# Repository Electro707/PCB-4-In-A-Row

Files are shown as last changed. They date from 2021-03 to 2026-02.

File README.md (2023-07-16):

# PCB Digital 4-In-A-Row

This a PCB is a soldering kit for a 4-In-A-Row game. A simple game consisting of 2 boards: one for the driver and one for the LEDs.

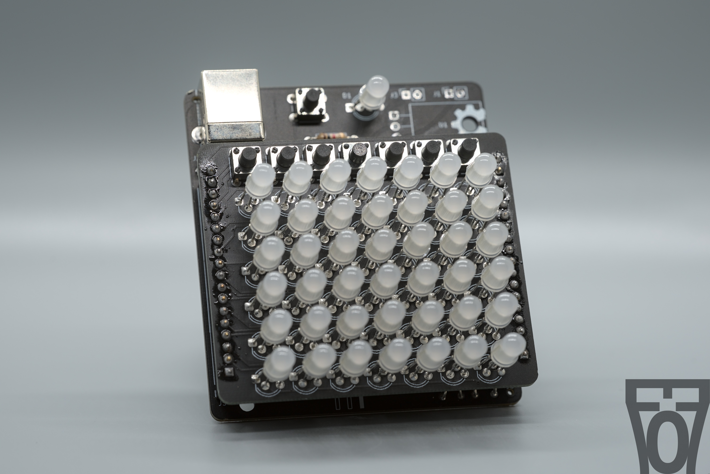
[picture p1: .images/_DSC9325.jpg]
Latest Rev


## Kits Page
The dedicated webpage for this can be found at [https://kits.electro707.com/4_in_a_row/](https://kits.electro707.com/4_in_a_row/)

## Kit on Tindie
I am currently selling the kit on Tindie. The product page can be found at [https://www.tindie.com/products/28121/](https://www.tindie.com/products/28121/).

## Firmware
The firmware can be found in the [Firmware](Firmware) folder. To build and upload the program, see [FIRMWARE.md](FIRMWARE.md) for more details.

## License
This project is licensed under the MIT license. See the [LICENSE.md](LICENSE.md) file for details.
TL;DR: You can download and modify the project as you wish. I simply ask you publish your fork or try and merge back to this repo (even thought you are under no obligations to do so).

## Changelog 
See [CHANGELOG.md](CHANGELOG.md) for changes info.

## Previous/Archived Repo
This project used to be in another repo before I archived it. The reason for the archive is I wanted to start properly using git as a version manager (instead of different folders) as well as a project cleanup. Think of it as a new start to this project.
The previous project repo can be found here: [https://github.com/Electro707/PCB-4-In-A-Row-ARCHIVE](https://github.com/Electro707/PCB-4-In-A-Row-ARCHIVE)

## Other Images

Latest Rev

With Panel (not actually updated, just made it once):
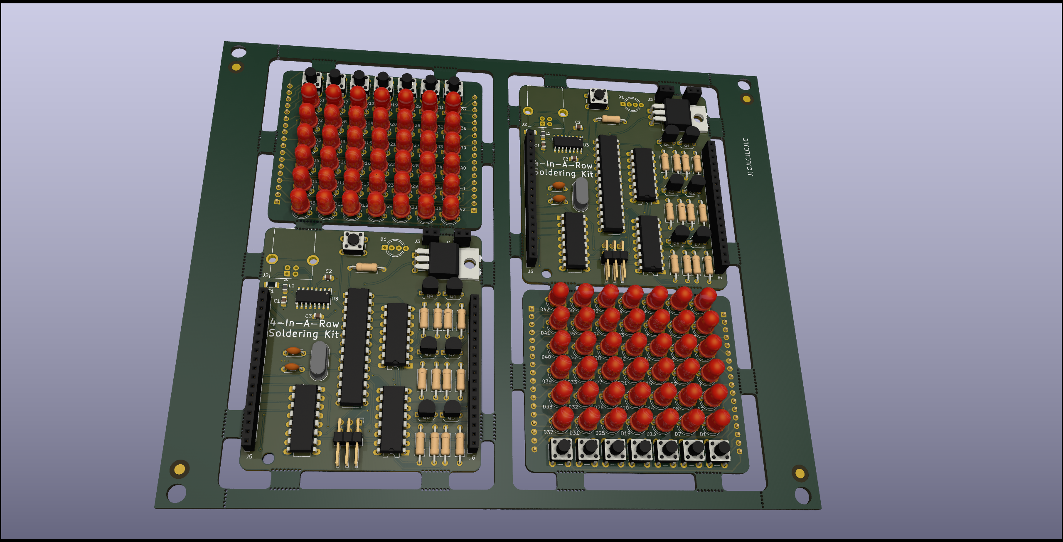
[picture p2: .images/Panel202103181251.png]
Panel Picture


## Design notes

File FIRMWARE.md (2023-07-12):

# Firmware Notes
This is the firwmare for the 4-in-a-row soldering kit. The revision number can be found in the git tags in this repository, tagged with fw_xxx.

## Arduino Comaptibility
The firmware is originally designed to only be built with the make file. With that said, the firmare is designed to be compatible with the Arduino IDE to build and upload. Just open [Firmware.ino](Firmware/Firmware.ino) with the IDE.
To upload the program, it is recommended to use the [MiniCore](https://github.com/MCUdude/MiniCore) hardware package to build and program to the IC. If using that, ensure that the external 16Mhz clock (default) is selected for the Clock setting.

## Build Requirements (non-Arduino)
If you would like to use the makefile to program and upload this firmware, you would need `avr-gcc` and `avrdude`. They can be downloaded from your package repository if you are using a sane operating system (GNU/Linux). If you are using MacOS, you should be able to get them thru brew, but I haven't checked. If you are on Windows, good luck!

## Make Commands:
- *default/no arguments*: **build** and **size**
- quick: **build** -> **size** -> **program**
- build: Builds the firmware
- size: Shows the RAM and FLASH usage of the built firmware
- program: Uploads the firmware over Arduino-As-ISP over /dev/ttyUSB0. To modify this, edit the makefile
- clean: Cleans the build files
- docs: Builds the doxygen documentation page

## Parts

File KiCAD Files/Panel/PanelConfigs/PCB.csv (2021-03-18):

Comment | Designator | Footprint | LCSC
100nF | C1,C2,C3 | Capacitor_SMD:C_0805_2012Metric_Pad1.18x1.45mm_HandSolder | C49678
Polyfuse | F1 | Fuse:Fuse_1206_3216Metric_Pad1.42x1.75mm_HandSolder | C369159
BLM21AG102SN1D | L1 | Inductor_SMD:L_0805_2012Metric_Pad1.15x1.40mm_HandSolder | C97001
CH340C | U3 | Package_SO:SOIC-16_3.9x9.9mm_P1.27mm | C84681

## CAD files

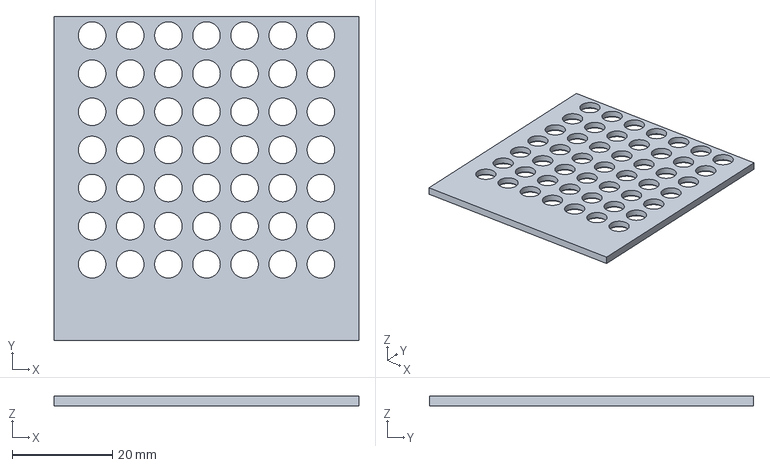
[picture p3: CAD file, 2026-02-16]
CAD/LED-Holder-Fixture/LedFixture.FCStd
61.0 x 64.8 x 2.00 mm

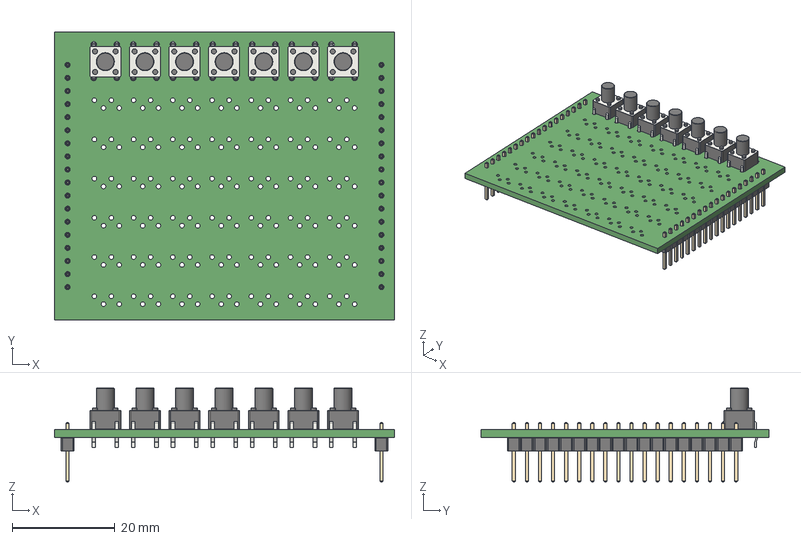
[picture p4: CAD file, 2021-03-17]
KiCAD Files/LED PCB/LED_PCB.step
66.0 x 55.9 x 18.2 mm

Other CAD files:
CAD/LED-Holder-Fixture/LedFixture-BodyChamfer.stl

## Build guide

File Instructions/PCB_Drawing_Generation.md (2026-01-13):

# How to generate drawings of the PCBs

To generate the top-down view of the PCBs, simply run `generate_pcb_svg.sh`.

To generate the step-by-step instructions, run:
`pcbdraw populate populate_driver.md step_by_step`.

You will need [pcbdraw](https://github.com/yaqwsx/PcbDraw) installed, preferable [my fork](https://github.com/Electro707/PcbDraw) as I incorporated some fixes.

On top of that, you will also need my [pcbdraw-lib fork](https://github.com/Electro707/PcbDraw-Lib/tree/e707) on the `e707` branch. You will need to modify the generate script to point "/home/electro/Documents/git/PcbDraw-Lib/KiCAD-base" to the location of the downloaded pcbdraw-lib fork. I do plan on creating PRs to merge the drawings I made upstream.

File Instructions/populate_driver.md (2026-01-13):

---
params:
    - --remap "../KiCAD Files/Driver PCB/pcbdraw_remap.json"
    - --resistor-flip "R15,R14,R13,R12,R11,R10"
    - --libs /mnt/aux1/git/PcbDraw-Lib/KiCAD-base
    - -s set-black-hasl
imgname: step_drawings/populating_{}.png
template: html_template
type: html
board: "../KiCAD Files/Driver PCB/PCB.kicad_pcb"
initial_components:
    - F1
    - L1
    - C1
...

# Soldering Guide - Main Driver

This page guides you through soldering a 4-in-a-row kit's main board, step by step.

These steps are my recommendation, but feel free to deviate of a certain order is easier for you!

- [[front | ]] We get the empty board
- [[front | R3-R9]] I recommend to solder all resistors first, as they are the thinest component and thus you can lay the board down with the resistors populated while soldering. I started with 1k&#8486; resistors, but you can choose any order
- [[front | R10-R15]] Then we solder the next set of resistor values, which are 100&#8486;
- [[front | Q1-Q6]] Then we populate all 2N3904 transistors
- [[front | C4-C5]] We populate the 12pF capacitors for the crystal
- [[front | Y1]] And then the crystal itself
- [[front | U2-U6]] Then we populate the ICs. In this drawing, the ICs are directly shown. THIS IS NOT RECOMMENDED. Instead, use the pin headers, and then push the component into them.
- [[front | SW1]] Then we populate the switch
- [[front | D1]] And the main indicator diode
- [[front | J2]] The USB connector
- [[front | J5,J6]] Then finally, the side pin sockets that will interconnect to the main board
- [[front | U1]] OPTIONALLY, solder U1 if you intend to use an external 7-12v source (such as a 9v battery)

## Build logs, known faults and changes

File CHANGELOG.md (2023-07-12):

This document describes the changes between the different revision. There is a previous [OLDER REPO](https://github.com/Electro707/PCB-4-In-A-Row-ARCHIVE) for this project, as mentioned in this repo's [README.md](../README.md)

- PCB rev:
    - V0.9: Initial commit to this repo (used to be known as RevB5 in the previous repo). The reason it's not a 1.0 is because I would to order a test board before releasing the design as complete.
    - V1.0: Initial completed release
- Firmware rev:
    - V0.9: Initial commit to this repo (used to be known as RevB5 in the previous repo). The reason it's not a 1.0 is because I want to test the firmware with the upcomming V1.0 of the board before a 1.0 release.
    - V1.0: Initial completed release

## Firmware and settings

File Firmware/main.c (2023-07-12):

/**
 * \mainpage
 * \section Intro Intro
 * This program is for the 4-In-A-Row Soldering Kit
 * \author Electro707(Jamal Bouajjaj)
 * \copyright MIT License
 * 
 * \section main_f Main File
 * Checkout main.c for all of the program.
 * 
 * \section int_update Interrupt Update
 * The shift register (and thus the LEDs) are updated from an internal timer. This timer interrupts once
 * every 128 uS ((1/16Mhz)*8*256). 
 * When the interrupt is ran, the LEDs are updated one color at a time (red, green, then blue) per row defined by the RGB mask
 * variable mask_test. This is needed as if a red and green LED are on at the same time, the green LED will never turn on due to
 * the red LED's lower foward voltage.
 * After all 3 colors are updated per row, the next row is selected (the cathodes for that row is pulled low). This keeps on running
 * until the last row is done, in which the process is repeated again.
 * With a nice trick of the human eye called presistance of vision, this is enough to trick us into thinking all of the LEDs
 * are on at the same time.
 */
/**
 * \file main.c
 * The main program file (The only file)
 */
/****************************************************************************************************
    Defines
****************************************************************************************************/

/**Set the CPU frequency to 16Mhz*/
#define F_CPU 16000000 
/**The number of times to blink the winner "chips" at the end of the game*/
#define WINNER_NUMB_WIN 5

/****************************************************************************************************
    Macros
****************************************************************************************************/
/**Macro to enable the SPI periferal*/
#define SPI_ENABLE SPCR |= 1<<6     
/**Macro to disable the SPI periferal*/
#define SPI_DISABLE SPCR &= ~(1<<6) 

/**Macro to enable the 74HC595's output*/
#define ENABLE_595_OUTPUT PORTB &= ~(1<<2) 
/**Macro to disable the 74HC595's output*/
#define DISABLE_595_OUTPUT PORTB |= (1<<2) 

/**Macro send data to the SPI bus,the wait until the periferal is ready for the next data*/
#define SEND_DATA_AND_WAIT(_DATA) SPDR = _DATA; while(!(SPSR & (1<<SPIF))) 
/**Macro that switches the active player variable to 1 or 2 depending on it's current state*/
#define SWITCH_ACTIVE_PLAYER active_player = (active_player == 1) ? 2 : 1
/**Macro to get the LED color depending of which player is selected (1 or 2)*/
#define PLAYER_COLOR_SELECTOR(_PLAYER) (_PLAYER == 0b01) ? 0b001 : 0b011

/****************************************************************************************************
    Includes
****************************************************************************************************/
#include <avr/io.h>
#include <util/delay.h>
#include <avr/interrupt.h>

/****************************************************************************************************
    Global Variables
****************************************************************************************************/
/**
 * An array to store the each LED's color for each row.
 * 
 * This variable is directly pushed unto the shift registers
 */
uint32_t led[6];                /**< The shift register's output bits per scan*/
uint8_t current_row = 0;        /**< The current row from 0-5 */
uint32_t current_led = 0;       /**< The current output mask 0-2 (See ISR(TIMER0_OVF_vect) for more details)*/
uint8_t status_led_color = 0;   /**< The status's LED color */
/**
 * Store the player locations's in this array.
 * 
 * Each dimension of this array is a row, and in each element the columns are in groups of 2 bits.\n
 * For example, 0b001000 for row #0 means that player 2 is on the second column fo row 0. 
 */
uint16_t players[6];        
uint8_t active_player = 0; /**< Stores the active player. 1 for player 1, 2 for player 2. \todo: have this be of an enum type */
/**
 * Store the row and column of the "chips" that made a player won in order to blink them
 */
uint8_t winner_location[2][4];

/**
 * A mask variable to mask the leds and status_led_color with red, green, then blue (as only the red,
 * green, or blue LEDs can be on at a time due to the common-cathode).
 * \todo Option to "reduce brightness" by software reducing duty cycle (maybe add a dummy mask of 0's ?)
 */
uint32_t mask_test[] = {
	0b001001001001001001001001,
	0b010010010010010010010010,
	0b100100100100100100100100,
};

/****************************************************************************************************
    Function Prototypes
****************************************************************************************************/
void reset_shift_registers(void);
void playerToLed(void);
int waitForButtonInput(void);
void clearBuffer(uint16_t *c, int array_lenght);
uint8_t checkForWinner(void);
void end_of_game(uint8_t who_won);
void fill_display_led(uint8_t color);

/**
 * The main function
 */
int main(void)
{
	// Set the LED sink pins to a low output and high impedance
	PORTC = 0;
	DDRC = 0b111111;
	// Set the buttons to input pull-up
	DDRD = 0x00;
	PORTD = 0xFF;
	// Set up PORTB pins
	DDRB |= 0b00101111; // Set all pins to output except for crystal, MISO, and PB0
	reset_shift_registers();
	PORTB |= 1<<4; // Due to SRCLR pin being controlled by SPI, it now has a pull-up to avoid it going LOW
	DISABLE_595_OUTPUT;
	// Set up SPI module
	SPCR = 0b00010000; // Master mode - Highest clock
	SPSR |= 1<<0; // Enable clock 2x multiplication
	// Set up update timer
	TCCR0B = 2; // Set divider to CLK/8
	TIMSK0 = 0x01; // Set time interrupt
	
	// Clear LEDs variable
	for(int i=0;i<6;i++){led[i] = 0;}
	
	PORTB &= ~(1<<0);	// Enable the status LED's cathode
	
	SPI_ENABLE;	
	sei();			// Turn on interrupts
	ENABLE_595_OUTPUT;	// Enable the 595's output driver

 	clearBuffer(players, 6);		// Clear the player's buffer for a fresh start
 	active_player = 1;			// Set the active player to player 1
 	status_led_color = PLAYER_COLOR_SELECTOR(active_player);
    // A 2D array to determine where the winner's "chips" are at to blink them
    // The second dimension is for the row and column, then the first dimension is the row/column locations
    while (1){ // The game loop!
        int c = waitForButtonInput();
        if(c == 7){             // If we press the button on the driver board which resets the game
            end_of_game(0);
            continue;
        }
 	
        _delay_ms(75);		// Delay for button noise
        int foundRow = 0;		// Variable to store if the lowest row has been found thru the for loop
        if(((players[0] >> (c*2)) & 0b11) == 0){		// Only switch player and find the row if the column isn't fully occupied
            for(int r=1;r<6;r++){		// Cycle thru all but one row
                players[r-1] |= active_player << (c*2);		// Set the row LED on of the last row on the loop
                if(r != 1){players[r-2] &= ~(0b11 << (c*2));}		// If the loop isn't the first one, set the last last row off
                playerToLed();		// Update the LED array to showcase the animation
                if(((players[r] >> (c*2)) & 0b11) != 0){		// If the row is occupied, exit the loop ( the led should be set from the last 2 lines)
                    foundRow = 1;		// Set the foundRow variable to a 1
                    break;		// Break out of the for loop
                }
                _delay_ms(75);		// Delay for animation
            }
            if(foundRow == 0){		// If didn't find the non-ocupied row, must be the last one
                players[5] |= active_player << (c*2);
                players[5-1] &= ~(0b11 << (c*2));
                playerToLed();
            }
            //number_of_turns++;			// Increase the number of turns
            uint8_t w = checkForWinner();	// Check for who, or none, player that wone
            if(w != 0){
            	end_of_game(w);
            	continue;
        	}
        	SWITCH_ACTIVE_PLAYER;		// Switch the active player if the row isn't fully occupied
            status_led_color = PLAYER_COLOR_SELECTOR(active_player);
        }
    }
}


/**
 * This function ends the game by blinking the LED that made the player won,
 * then resets some variables
 * 
 * \param who_won The player who won the game if anybody won.\n
 * 0 For nobody\n
 * 1 For player 1\n
 * 2 For player 2
 */
void end_of_game(uint8_t who_won){
    // Blink thru the "chips" that won
    if (who_won!=0){
        //led_color = PLAYER_COLOR_SELECTOR(who_won);
        for(int i=0;i<WINNER_NUMB_WIN;i++){
            for(int k=0;k<4;k++){
                players[winner_location[0][k]] &= ~(0b11 << (winner_location[1][k]*2));
            }
            playerToLed();
            _delay_ms(400);
            for(int k=0;k<4;k++){
                players[winner_location[0][k]] |= (active_player << (winner_location[1][k]*2));
            }
            playerToLed();
            _delay_ms(400);
        }
    }
    else{
        uint8_t led_color = 0b111;
        fill_display_led(led_color);
        for(int i=0;i<5;i++){
            status_led_color = 0;
            _delay_ms(400);
            status_led_color = led_color;
            _delay_ms(400);
        }
    }
    
    // Used to wait until the player pressed the button before the game reset
    /* 
    while(1){	// Wait until button is pressed to reset game
        int c = waitForButtonInput();
        if(c == 7){		// If pressed the button right of the indicator
            // Reset the variables
            active_player = 1;
            //number_of_turns = 0;
            // Clear the buffer
            clearBuffer(players, 6);
            playerToLed();
            _delay_ms(500);
            // Exit out of this loop to return to the game loop
            break;
        }
    }*/
    fill_display_led(0);
    clearBuffer(players, 6);
    active_player = 1;
    status_led_color = PLAYER_COLOR_SELECTOR(active_player);
}

/**
 * A function that resets the shift register thru pin PB4
 * Because that pin is set to an input no matter what when the SPI periferal
 * is enabled, we must disable it before we're able to control the pin
 */
void reset_shift_registers(void){
	SPI_DISABLE; // Disable SPI so it doesn't override pin
	DDRB |= 1<<4; // Set reset pin as output
	PORTB |= 1<<4; // Set reset pin HIGH
	_delay_ms(20);
	PORTB &= ~(1<<4); // Set reset pin LOW
	_delay_ms(20);
	PORTB |= 1<<4; // Set reset pin HIGH
	_delay_ms(20);
	DDRB &= ~(1<<4); // Set reset pin as input
}

/**
 * A function that converts the players array into the led array in order to be
 * outputed.
 * Because I wanted to prevent any flicker effect while the array is beign updated,
 * the interupts (the only one that exists is the LED updater one) are disabled while
 * the led array is beign eidted.
 */
void playerToLed(void){
	cli();
	for(int r=0;r<6;r++){
		led[r] = 0L; // Clear LED buffer
		for(int c=0;c<7;c++){
			uint8_t playerAtLoc = (players[r] >> (c*2)) & 0b11;
			uint8_t to_shift = 0;
			if(playerAtLoc != 0){
                to_shift = PLAYER_COLOR_SELECTOR(playerAtLoc);
            }
			led[r] |= ((uint32_t)to_shift << (c*3));
		}
	}
	sei();
}

/**
 * A function that waits until one of the buttons are pressed 
 * (either the column buttons or the generic button).
 * 
 * \return A number 0-6 corresponding to the column button pressed
 * or 7 for the general button
 */
int waitForButtonInput(void){
	while(PIND == 0xFF);
	for(int i=0;i<8;i++){	// Look for the button number that is pressed
		if(((PIND >> i) & 0b1) == 0){
			return i;
		}
	}
	return 0;
}

/**
 * A function that clears a 16-bit buffer with a given array_lenght
 * \todo Turn this into a macro
 */
void clearBuffer(uint16_t *c, int array_lenght){
	for(int i=0;i<array_lenght;i++){
		c[i] = 0;
	}
}

/**
 * A function that fills the entire display with a certain color
 * \param color The color to turn the display into. Need to be only 3-bits in size
 */
void fill_display_led(uint8_t color){
    cli();
	for(int r=0;r<6;r++){
        led[r] = 0L;
		for(int c=0;c<7;c++){
			led[r] |= ((uint32_t)color << (c*3));
		}
	}
	sei();
}

/**
 * A function to check for a game winner
 * \return 0 if no player won, 1 for player 1, and 2 for player 2
 * \note Thanks Spencer Hopwood for this function :)
 */
uint8_t checkForWinner(){
    int c, r, i;
	// Check vertical
	for(c=0;c<7;c++){		// Check every column
		uint8_t similarCounter = 0;		// Stores the number of same player in a row
		uint8_t simlarPlayer = 0;		// Stores the player for the previous variable
		for(r=0;r<(6-1);r++){
			if( ((players[r]>>(c*2)) & 0b11) == ((players[r+1]>>(c*2)) & 0b11) ){		// If the player from the current and next row is the same, increment a counter
				if(((players[r]>>(c*2)) & 0b11) != 0){   		// Only increment counter if the player isn't 0 (none)
					simlarPlayer = (players[r]>>(c*2))&0b11;	// Record the similar player
					winner_location[0][similarCounter] = r;
                    winner_location[1][similarCounter] = c;
					similarCounter++;							// Increment counter
					if(similarCounter >= 3){					// If counter is increment to 3 ( repreating player 4 times), return
						break;
					}
				}
			}
			else{			// If the player isn't the same as the next row, reset the counter and player variable
				similarCounter = 0;
				simlarPlayer = 0;
			}
		}
		// If there was a similarity, exit and return the player number
		if(similarCounter >= 3){
            winner_location[0][similarCounter] = r+1;
            winner_location[1][similarCounter] = c;
			return simlarPlayer;
		}
	}

	// Check horizontal
	for(r=0;r<6;r++){		// Check every row
		uint8_t similarCounter = 0;		// Stores the number of same player in a column
		uint8_t simlarPlayer = 0;		// Stores the player for the previous variable
		for(c=0;c<(7-1);c++){
			if( ((players[r]>>(c*2)) & 0b11) == ((players[r]>>((c+1)*2)) & 0b11) ){		// If the player from the current and next column is the same, increment a counter
				if(((players[r]>>(c*2)) & 0b11) != 0){   		// Only increment counter if the player isn't 0 (none)
					simlarPlayer = (players[r]>>(c*2))&0b11;	// Record the similar player
					winner_location[0][similarCounter] = r;
                    winner_location[1][similarCounter] = c;
					similarCounter++;							// Increment counter
					if(similarCounter >= 3){					// If counter is increment to 3 ( repreating player 4 times), return
						break;
					}
				}
			}
			else{			// If the player isn't the same as the next row, reset the counter and player variable
				similarCounter = 0;
				simlarPlayer = 0;
			}
		}
		// If there was a similarity, exit and return the player number
		if(similarCounter >= 3){
            winner_location[0][similarCounter] = r;
            winner_location[1][similarCounter] = c+1;
			return simlarPlayer;
		}
	}

	// Check diagonal (positive slope)
	// Check 4 diagonal in a row from the last 3 row and the first 4 column ( the only combination)
	for(c=0;c<4;c++){
		for(r=3;r<6;r++){
			uint8_t similarCounter = 0;		// Stores the number of same player in a column
			uint8_t simlarPlayer = 0;		// Stores the player for the previous variable
			for(i=0;i<(4-1);i++){
				if( ((players[r-i]>>((c+i)*2)) & 0b11) == ((players[r-i-1]>>((c+i+1)*2)) & 0b11) ){		// If the player from the current and next column is the same, increment a counter
					if(((players[r-i]>>((c+i)*2)) & 0b11) != 0){   		// Only increment counter if the player isn't 0 (none)
						simlarPlayer = (players[r-i]>>((c+i)*2)) & 0b11;	// Record the similar player
						winner_location[0][similarCounter] = r-i;
                        winner_location[1][similarCounter] = c+i;
						similarCounter++;							// Increment counter
						if(similarCounter >= 3){					// If counter is increment to 3 ( repreating player 4 times), return
							break;
						}
					}
				}
				else{			// If the player isn't the same as the next row, reset the counter and player variable
					similarCounter = 0;
					simlarPlayer = 0;
				}
			}
			// If there was a similarity, exit and return the player number
			if(similarCounter >= 3){
                winner_location[0][similarCounter] = r-i-1;
                winner_location[1][similarCounter] = c+i+1;
				return simlarPlayer;
			}
		}
	}

	// Check diagonal (negative slope)
	// Check 4 diagonal in a row from the last 3 row and the first 4 column ( the only combination)
	for(c=6;c>2;c--){
		for(r=3;r<6;r++){
			uint8_t similarCounter = 0;		// Stores the number of same player in a column
			uint8_t simlarPlayer = 0;		// Stores the player for the previous variable
			for(i=0;i<(4-1);i++){
				if( ((players[r-i]>>((c-i)*2)) & 0b11) == ((players[r-i-1]>>((c-i-1)*2)) & 0b11) ){		// If the player from the current and next column is the same, increment a counter
					if(((players[r-i]>>((c-i)*2)) & 0b11) != 0){   		// Only increment counter if the player isn't 0 (none)
						simlarPlayer = (players[r-i]>>((c-i)*2)) & 0b11;	// Record the similar player
						winner_location[0][similarCounter] = r-i;
                        winner_location[1][similarCounter] = c-i;
						similarCounter++;							// Increment counter
						if(similarCounter >= 3){					// If counter is increment to 3 ( repreating player 4 times), return
							break;
						}
					}
				}
				else{			// If the player isn't the same as the next row, reset the counter and player variable
					similarCounter = 0;
					simlarPlayer = 0;
				}
			}
			// If there was a similarity, exit and return the player number
			if(similarCounter >= 3){
                winner_location[0][similarCounter] = r-i-1;
                winner_location[1][similarCounter] = c-i-1;
				return simlarPlayer;
			}
		}
	}
	return 0;
}

/**
 * The LED updater interupt, beign triggered by Timer0
 * 
 * The LEDs are updated by using the shift registers, only turning on the red, green, then blue LEDs
 * during each row update.
 */
ISR(TIMER0_OVF_vect){
	PORTB &= ~(1<<1);
	//uint32_t to_s = (uint32_t)led[current_row] & (1L<<current_led);
	uint32_t to_s = ((uint32_t)led[current_row] | ((uint32_t)status_led_color << 21)) & mask_test[current_led];
	SEND_DATA_AND_WAIT(to_s >> 16);
	SEND_DATA_AND_WAIT(to_s >> 8);
	SEND_DATA_AND_WAIT(to_s >> 0);
	PORTB |= (1<<1);
	//if (++current_led == 12){
	if (++current_led == 3){
		current_led = 0;
		if (++current_row == 6){
			current_row = 0;
		}
		PORTC = 1<<current_row;
	}
}

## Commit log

2021-03-17 Initial Commit for this repo
    [LED_PCB.step, PCB.kicad_pcb, PCB.kicad_sch]
2021-03-18 Added panelized version of board. Change FTDI IC to a CH340
    [PCB.kicad_pcb, PCB.kicad_sch, PanelTemplate.kicad_pcb]
2021-03-18 Finalized the panel stuff
    [ComponentPlacement.csv, PCB.csv, PCB.kicad_pcb]
2021-04-20 Updated schematic. Added tooloing hole for driver for potential assembly. Added rev number
    [PCB.kicad_pcb, PCB.kicad_sch]
2021-12-30 Updated KiCAD files for KiCAD 6
    [PCB.kicad_pcb, PCB.kicad_sch]
2022-03-26 Updated instructions and script to generate a drawing of the PCB with pcbdraw
    [PCB.kicad_pcb]
2023-06-07 Updated instructions. Up-rev in KiCAD files
2023-07-06 Updated titleblock. Fixed R9 value on driver. Added polyfuse's part number
    [PCB.kicad_sch]
2023-07-12 Merged C and Arduino-compatible program into one Arduino references now C file Added Firmware notes Updated README
2024-01-06 Updated so the voltage regulator text is correct
2024-01-06 Udded an LED fixture drawings
2025-08-16 Added LED holder fixture for easier soldering
    [LedFixture-BodyChamfer.stl, LedFixture.FCStd]
2026-01-13 Updated instructions NO UPDATED TO PCB ARTWORK, but updated files to latest KiCAD version and changed the pcb attribute to include right resistor value
    [PCB.kicad_pcb, PCB.kicad_sch, PCB.step]
2026-01-13 Added new make target for fuses only
2026-02-16 Moved a model over to a CAD folder. Updated gitignore to ignore generated svgs
    [LedFixture-BodyChamfer.stl, LedFixture.FCStd]
